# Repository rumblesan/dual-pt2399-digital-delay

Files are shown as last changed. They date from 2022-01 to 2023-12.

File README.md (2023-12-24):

# Dual PT2399 Digi Delay

A delay module designed for the Loudest Warning 4U format

## Description

Built around two PT2399 delay chips.
Inspired equally by the Serge WAD and the Strega, it does clean pretty well but also pushes into the usual 2399 weirdness.

## Features

 * Dual PT2399 delays
 * Single input with gain control and mild overdrive when past about 1 o'clock
 * Switch to have delays in series or parallel
 * Delay can go from short as I think I could manage to well into clicks and squeals territory
 * CV control over delay time of each independently, with attenuverters
 * CV control has an input range of -5 to +5 volts, which should cover the full range of the delay either way
 * Join switch to have delay 1 CV/knob control affect delay 2 as well
 * Independent full wet outputs for each delay
 * Independent mix levels for each delay and dry into main mix out, with additional overdrive on the delays when pushed past about 1 o'clock
 * Feedback can very easily push into self oscillation territory

## Power

+12 101ma
-12 35ma

## Signal Flow

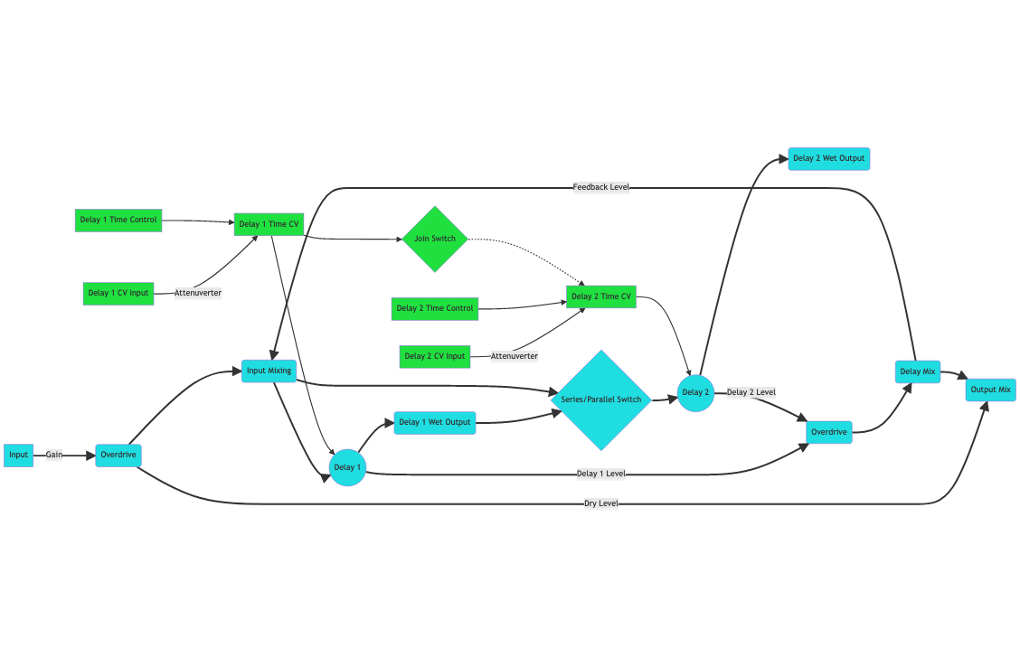
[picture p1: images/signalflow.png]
Signal flow diagram


## Front Panel

In the [panel](./panel) folder there are Front Panel Design files that can be used to order aluminium panels. One has the oval holes that fit the Johnson banana plugs, whilst the other just has circular holes.

There are also gerber files for a PCB front panel if required.

The Affinity Design and Inkscape SVG files are included in the repository as well in case you want to redesign things.

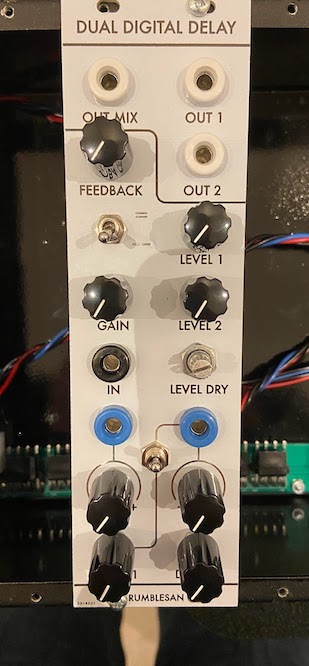
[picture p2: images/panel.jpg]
Module front panel


## Part Information

Everything *should* be pretty clear and obvious as far as construction goes, but the following may be useful info.

### Capacitors

Caps noted as X7R are ones that are for power decoupling. Feel free to use C0G ones if you want.
Caps noted as polypropylene are used in the input and output filters of the PT2399 delay chip. Any decent film should be fine, but you can probably use C0G ceramics if you want.
Electrolytic caps noted as audio are ones that are in the audio path, so worth getting decent quality ones.

### Banana Jacks

Designed to work with the Johnson banana jacks, but others probably work.

### Power Connector

The PCB footprint for the power connector is for a Molex KK-254 connector. In reality I've assumed people with likely have a flying cable with whatever they use on the end.

## Construction Notes

The boards sandwich together with all components inside. This means that all the capacitors on the delay board need to be lying flat against the PCB.

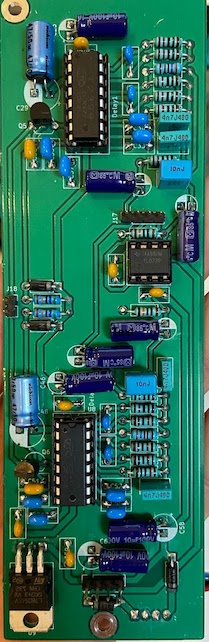
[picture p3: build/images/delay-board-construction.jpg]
Delay board construction


Depending on what part you use for the Join switch, the lower leg from that may extend far enough to hit IC U5 on the mid board, so snip it off.

## Fixes

Some of the older revisions have some minor errors. Check the [Fixes](./build/fixes.md) file for more information.

## Availability

[Pusherman](https://pushermanproductions.com/product/4u-rumblesan-dual-pt2399-digital-delay-3-x-pcb-fr4-panel/)
Synthcube coming soon

## Contact

Drop me an email at guy@rumblesan.com

## License

Creative Commons Licence
This work is licensed under a [Creative Commons Attribution 4.0 International License]("http://creativecommons.org/licenses/by/4.0/")

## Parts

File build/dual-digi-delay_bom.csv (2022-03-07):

Component | Description | Part | References | Value | Footprint | Quantity Per PCB | Vendor | Note | SKU
1 | Unpolarized capacitor | C | C2 C3 C7 C8 C9 C11 C17 C18 C19 C20 C23 C24 | 10pF | C_Rect_L7.0mm_W3.5mm_P5.00mm | 12
2 | Unpolarized capacitor | C | C13 C14 | 100pF | C_Rect_L7.0mm_W3.5mm_P5.00mm | 2
3 | Unpolarized capacitor | C | C27 C28 C49 C50 | 560pF | C_Rect_L7.0mm_W3.5mm_P5.00mm | 4
4 | Unpolarized capacitor | C | C30 C33 C35 C37 C52 C54 C55 C57 | 100nF | C_Rect_L7.0mm_W3.5mm_P5.00mm | 8
5 | Polarized capacitor | C_Polarized | C25 C46 C58 C60 | 10uF | CP_Radial_D6.3mm_P2.50mm | 4
6 | Polarized capacitor | C_Polarized | C29 C48 | 47uF | CP_Radial_D8.0mm_P3.50mm | 2
7 | Unpolarized capacitor | C | C1 C4 C5 C6 C10 C12 C15 C16 C21 C22 C26 C40 C41 C47 C56 C59 | 100nF (X7R) | C_Rect_L7.0mm_W3.5mm_P5.00mm | 16
8 | Unpolarized capacitor | C | C36 C45 | 10nF (polypropylene) | C_Rect_L7.0mm_W3.5mm_P5.00mm | 2
9 | Polarized capacitor | C_Polarized | C38 C39 C42 C43 | 10uF (Audio) | CP_Radial_D5.0mm_P2.50mm | 4
10 | Unpolarized capacitor | C | C32 C51 | 470nF (X7R) | C_Rect_L7.0mm_W3.5mm_P5.00mm | 2
11 | Unpolarized capacitor | C | C31 C34 C44 C53 | 4n7F (polypropylene) | C_Rect_L7.0mm_W3.5mm_P5.00mm | 4
12 | Diode | D | D1 D2 D3 D4 D5 D6 D7 D8 D9 D10 D11 D12 | 1N4148 | Diode_THT_P7.62mm_Horizontal | 12
13 | Diode | D | D15 D16 | 1N5818 | D_A-405_P10.16mm_Horizontal | 2
14 | Diode | D | D13 D14 | 1n4001 | D_A-405_P10.16mm_Horizontal | 2
15 | Potentiometer | R_Potentiometer | DELAY_CV_ATTV1 DELAY_CV_ATTV2 | 100kB | Potentiometer_Alpha_RD901F-40-00D_Single_Vertical_CircularHoles | 2 | Thonk
16 | Potentiometer | R_Potentiometer | DELAY_TIME1 DELAY_TIME2 | 25kB | Potentiometer_Alpha_RD901F-40-00D_Single_Vertical_CircularHoles | 2 | Thonk
17 | Potentiometer | R_Potentiometer | DRY_LEVEL1 FEEDBACK1 INPUT_GAIN1 WET_LEVEL1 WET_LEVEL2 | 50kB | Potentiometer_Alpha_RD901F-40-00D_Single_Vertical_CircularHoles | 5 | Thonk
18 | A Johnson panel mount banana jack | BananaJack_PanelMount | J1 J2 J3 J4 J5 J6 | BananaJack_PanelMount | BananaJack_THT_JohnsonCinch_108-09 | 6 | Mouser | BananaJack | 108-0901-1
19 | Generic connector, single row, 01x02, script generated (kicad-library-utils/schlib/autogen/connector/) | Conn_01x02_Male | J23 J25 J28 J31 | Conn_1x02_Pin | PinHeader_1x02_P2.54mm_Vertical | 4 |  | Delay Time Control Delay Out Output Audio Feedback Audio
20 | Generic connector, single row, 01x02, script generated (kicad-library-utils/schlib/autogen/connector/) | Conn_01x02_Female | J7 J8 J9 J18 | Conn_1x02_Skt | PinSocket_1x02_P2.54mm_Vertical | 4 |  | Output Audio Delay Out Feedback Audio Delay Time Control
21 | Generic connector, single row, 01x03, script generated (kicad-library-utils/schlib/autogen/connector/) | Conn_01x03_Male | J29 | Conn_1x03_Pin | PinHeader_1x03_P2.54mm_Vertical | 1 |  | Delay2 Source
22 | Generic connector, single row, 01x03, script generated (kicad-library-utils/schlib/autogen/connector/) | Conn_01x03_Female | J11 | Conn_1x03_Skt | PinSocket_1x03_P2.54mm_Vertical | 1 |  | Delay2 Source
23 | Generic connector, single row, 01x04, script generated (kicad-library-utils/schlib/autogen/connector/) | Conn_01x04_Male | J16 J24 J26 J30 J32 | Conn_1x04_Pin | PinHeader_1x04_P2.54mm_Vertical | 5 |  | Delay Send/Recv Mid Board Power Recv Delay Audio Top Board Power Recv Input Audio
24 | Generic connector, single row, 01x04, script generated (kicad-library-utils/schlib/autogen/connector/) | Conn_01x04_Female | J10 J12 J15 J17 J19 | Conn_1x04_Skt | PinSocket_1x04_P2.54mm_Vertical | 5 |  | Delay Audio Input Audio Mid Board Power Send Delay Send/Recv Lower Board Power Send
25 | Generic connector, single row, 01x06, script generated (kicad-library-utils/schlib/autogen/connector/) | Conn_01x06_Male | J27 J33 | Conn_1x06_Pin | PinHeader_1x06_P2.54mm_Vertical | 2 |  | Delay2 CV Delay1 CV
26 | Generic connector, single row, 01x06, script generated (kicad-library-utils/schlib/autogen/connector/) | Conn_01x06_Female | J13 J14 | Conn_1x06_Skt | PinSocket_1x06_P2.54mm_Vertical | 2 |  | Delay1 CV Delay2 CV
27 | Generic connector, single row, 01x04, script generated (kicad-library-utils/schlib/autogen/connector/) | Conn_01x04_Male | J20 | Molex_1x04_KK-254 | Molex_KK-254_AE-6410-04A_1x04_P2.54mm_Vertical | 1 |  | Main Power
28 | 0.2A Ic, 40V Vce, Small Signal NPN Transistor, TO-92 | 2N3904 | Q1 Q2 Q3 Q4 Q5 Q6 | 2N3904 | TO-92_Inline_Wide | 6
29 | Resistor | R | R1 R4 R8 | 330r | Resistor_THT_L6.3mm_D2.5mm_P10.16mm_Horizontal | 3
30 | Resistor | R | R19 R20 | 470r | Resistor_THT_L6.3mm_D2.5mm_P10.16mm_Horizontal | 2
31 | Resistor | R | R24 R25 R50 R51 | 1k | Resistor_THT_L6.3mm_D2.5mm_P10.16mm_Horizontal | 4
32 | Resistor | R | R26 R29 | 2k2 | Resistor_THT_L6.3mm_D2.5mm_P10.16mm_Horizontal | 2
33 | Resistor | R | R54 R66 | 2k7 | Resistor_THT_L6.3mm_D2.5mm_P10.16mm_Horizontal | 2
34 | Resistor | R | R2 R7 R46 R48 R52 R53 R55 R56 R57 R58 R63 R64 R65 R67 R68 R69 | 10k | Resistor_THT_L6.3mm_D2.5mm_P10.16mm_Horizontal | 16
35 | Resistor | R | R3 R11 | 15k | Resistor_THT_L6.3mm_D2.5mm_P10.16mm_Horizontal | 2
36 | Resistor | R | R30 R32 | 22k | Resistor_THT_L6.3mm_D2.5mm_P10.16mm_Horizontal | 2
37 | Resistor | R | R17 | 33k | Resistor_THT_L6.3mm_D2.5mm_P10.16mm_Horizontal | 1
38 | Resistor | R | R12 R13 R40 R41 R42 R43 | 47k | Resistor_THT_L6.3mm_D2.5mm_P10.16mm_Horizontal | 6
39 | Resistor | R | R44 R45 | 82k | Resistor_THT_L6.3mm_D2.5mm_P10.16mm_Horizontal | 2
40 | Resistor | R | R5 R6 R9 R10 R14 R15 R16 R18 R27 R28 R33 R34 R37 R38 R39 R47 R49 R59 R61 | 100k | Resistor_THT_L6.3mm_D2.5mm_P10.16mm_Horizontal | 19
41 | Resistor | R | R21 R31 R35 R36 | 220k | Resistor_THT_L6.3mm_D2.5mm_P10.16mm_Horizontal | 4
42 | Resistor | R | R22 R23 R60 R62 | 560k | Resistor_THT_L6.3mm_D2.5mm_P10.16mm_Horizontal | 4
43 | Switch, single pole double throw | SW_SPDT | SW1 SW2 | SW_SPDT | Toggle_Switch_100SP1T1B3M2QE | 2 | Mouser | Delay 2 Input CV Join | 612-100SP1T1B3M2QEH
44 | Positive 1.5A 35V Linear Regulator, Fixed Output 5V, TO-220/TO-263/TO-252 | L7805 | U9 | L7805 | TO-220-3_Horizontal_TabDown | 1
45 | Echo Processor IC | PT2399 | U6 U8 | PT2399 | DIP-16_W7.62mm_Socket | 2
46 | Dual Low-Noise JFET-Input Operational Amplifiers, DIP-8/SOIC-8 | TL072 | U1 U2 U3 U7 | TL072 | DIP-8_W7.62mm_Socket | 4
47 | Quad Low-Noise JFET-Input Operational Amplifiers, DIP-14/SOIC-14 | TL074 | U4 U5 | TL074 | DIP-14_W7.62mm_Socket | 2
Component Groups: | 47
Component Count: | 202
Fitted Components: | 202
Number of PCBs: | 1
Total components: | 202
Schematic Version: | v05
Schematic Date: | 2022-03-04
PCB Variant: | udefault
BoM Date: | Monday, 07 March 2022 at 15:22:20
Schematic Source: | dual-digi-delay.kicad_sch
KiCad Version: | Eeschema (6.0.0-0)

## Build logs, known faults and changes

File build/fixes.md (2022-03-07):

# Fixes

Fixes and caveats for any versions of the PCB that need them.

## Revision 5

No errors so far.

## Revision 4

The silkscreen for J16 is on the wrong side of the board. Make sure to install the pin header on the other side.

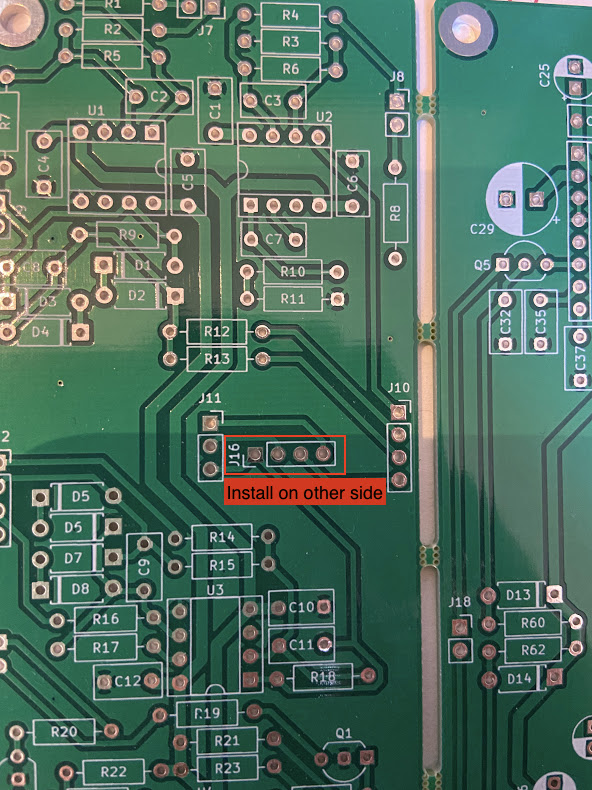
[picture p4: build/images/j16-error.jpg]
Revision 4 J16 fix


## Revision 3

The D16 polarity protection diode symbol is reversed on the PCB. Make sure to install with the cathode going to the power input.

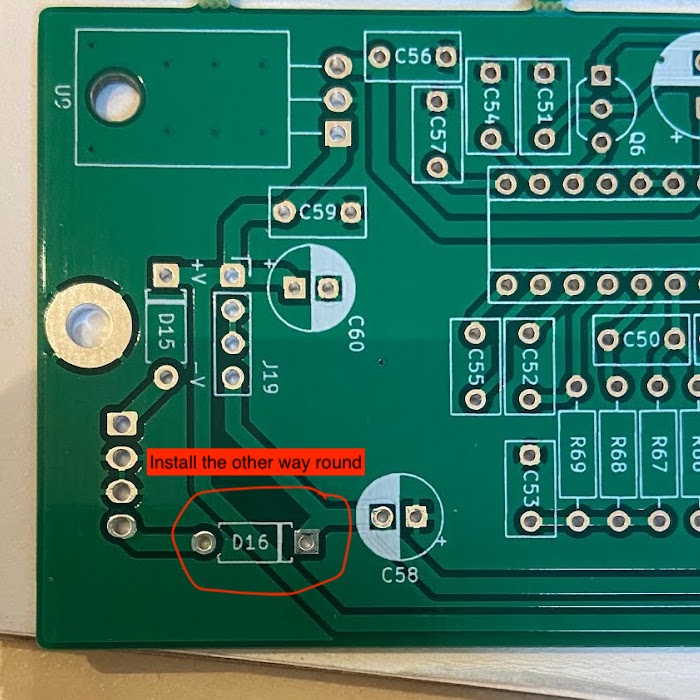
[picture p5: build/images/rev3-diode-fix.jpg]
Revision 3 diode fix


Also J16 error present in rev4 above.

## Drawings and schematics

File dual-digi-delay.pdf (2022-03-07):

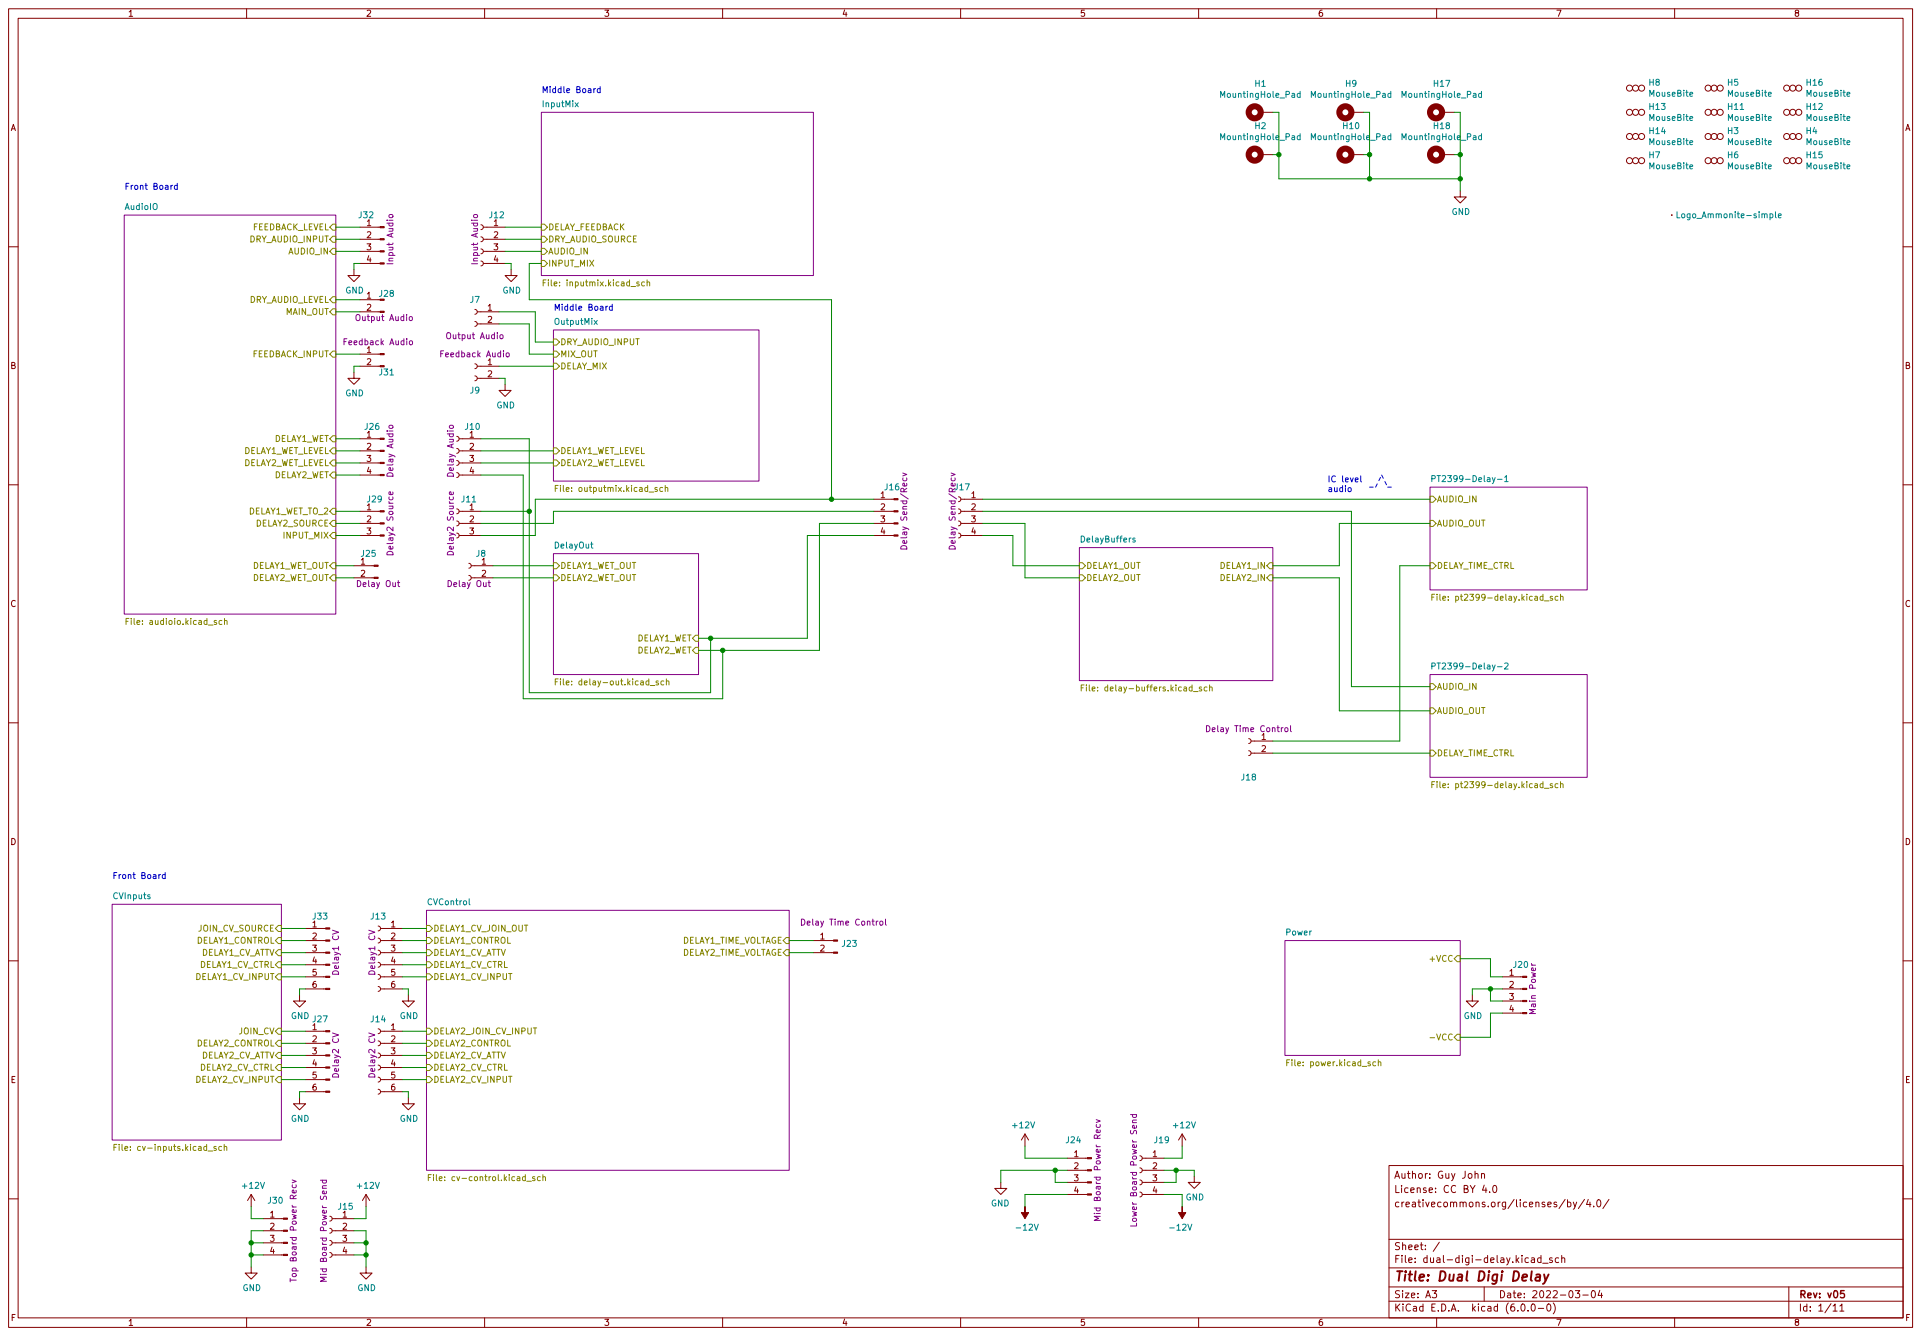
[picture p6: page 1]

H7MouseBite GND
File: delay-out.kicad_sch DELAY_MIX MIX_OUT DRY_AUDIO_INPUT DELAY2_WET_LEVEL DELAY1_WET_LEVEL OutputMix

File: delay-buffers.kicad_sch DELAY1_WET DELAY2_WET DELAY1_WET_OUT DELAY2_WET_OUT DelayOut

J18 Delay Time Control GND

File: dual-digi-delay.kicad_sch Sheet: / creativecommons.org/licenses/by/4.0/ License: CC BY 4.0 Author: Guy John DELAY1_CV_INPUT DELAY1_CV_ATTV

J19 Lower Board Power Send+12V

J30 Top Board Power Recv+12V
J15 Mid Board Power Send GND

Id: 1/11 Title: Dual Digi Delay

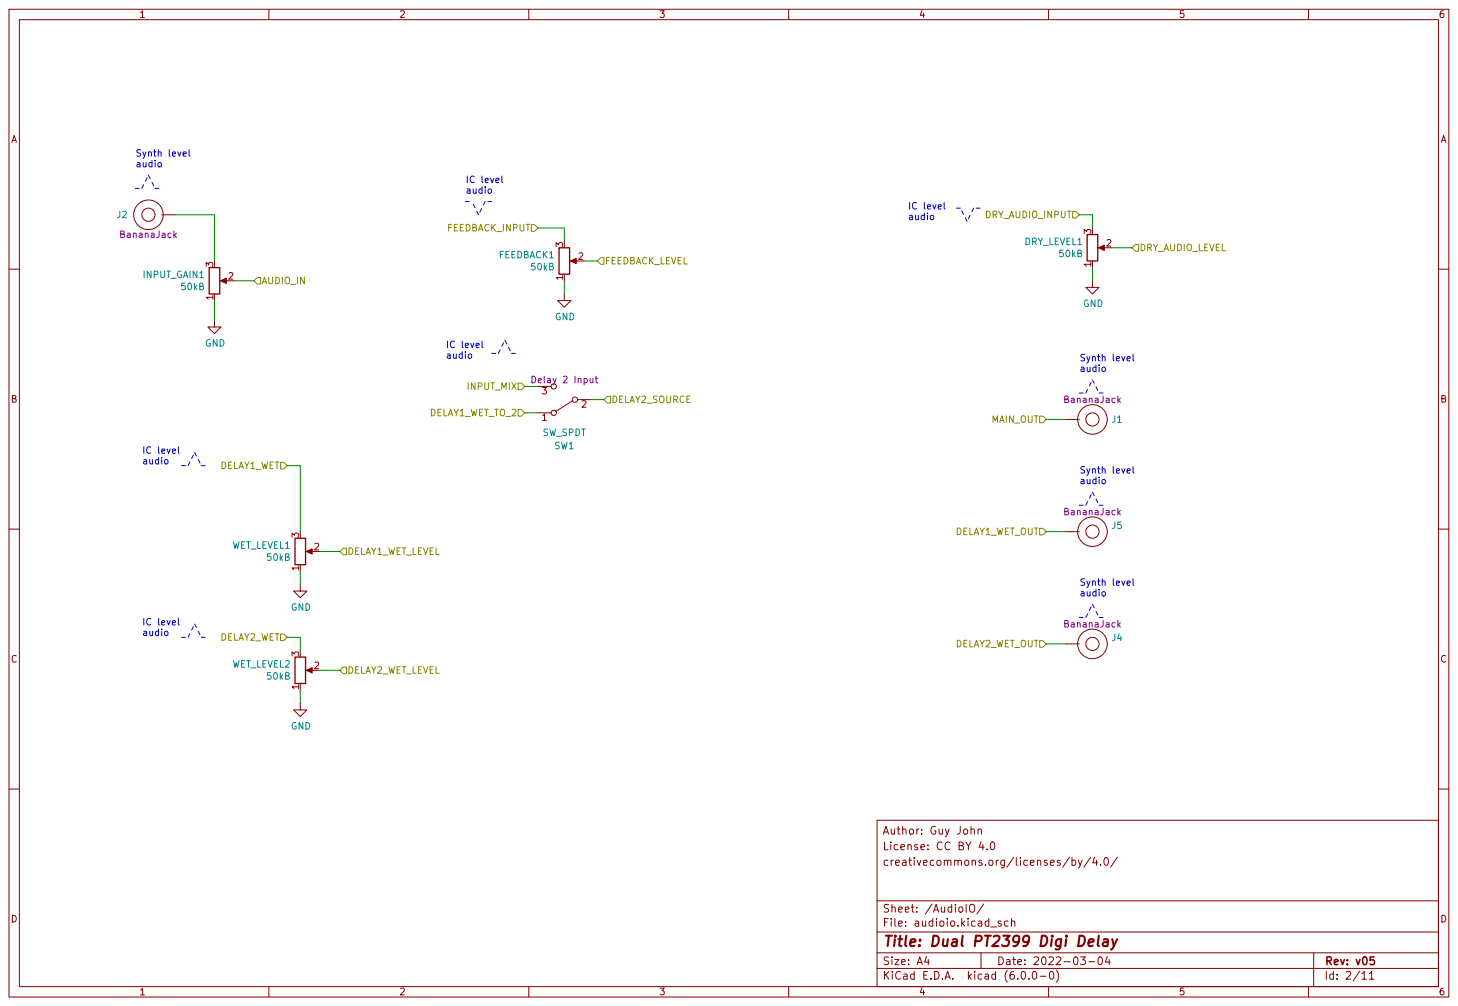
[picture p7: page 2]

File: audioio.kicad_sch Sheet: /AudioIO/ creativecommons.org/licenses/by/4.0/ License: CC BY 4.0 Author: Guy John

Id: 2/11 Title: Dual PT2399 Digi Delay

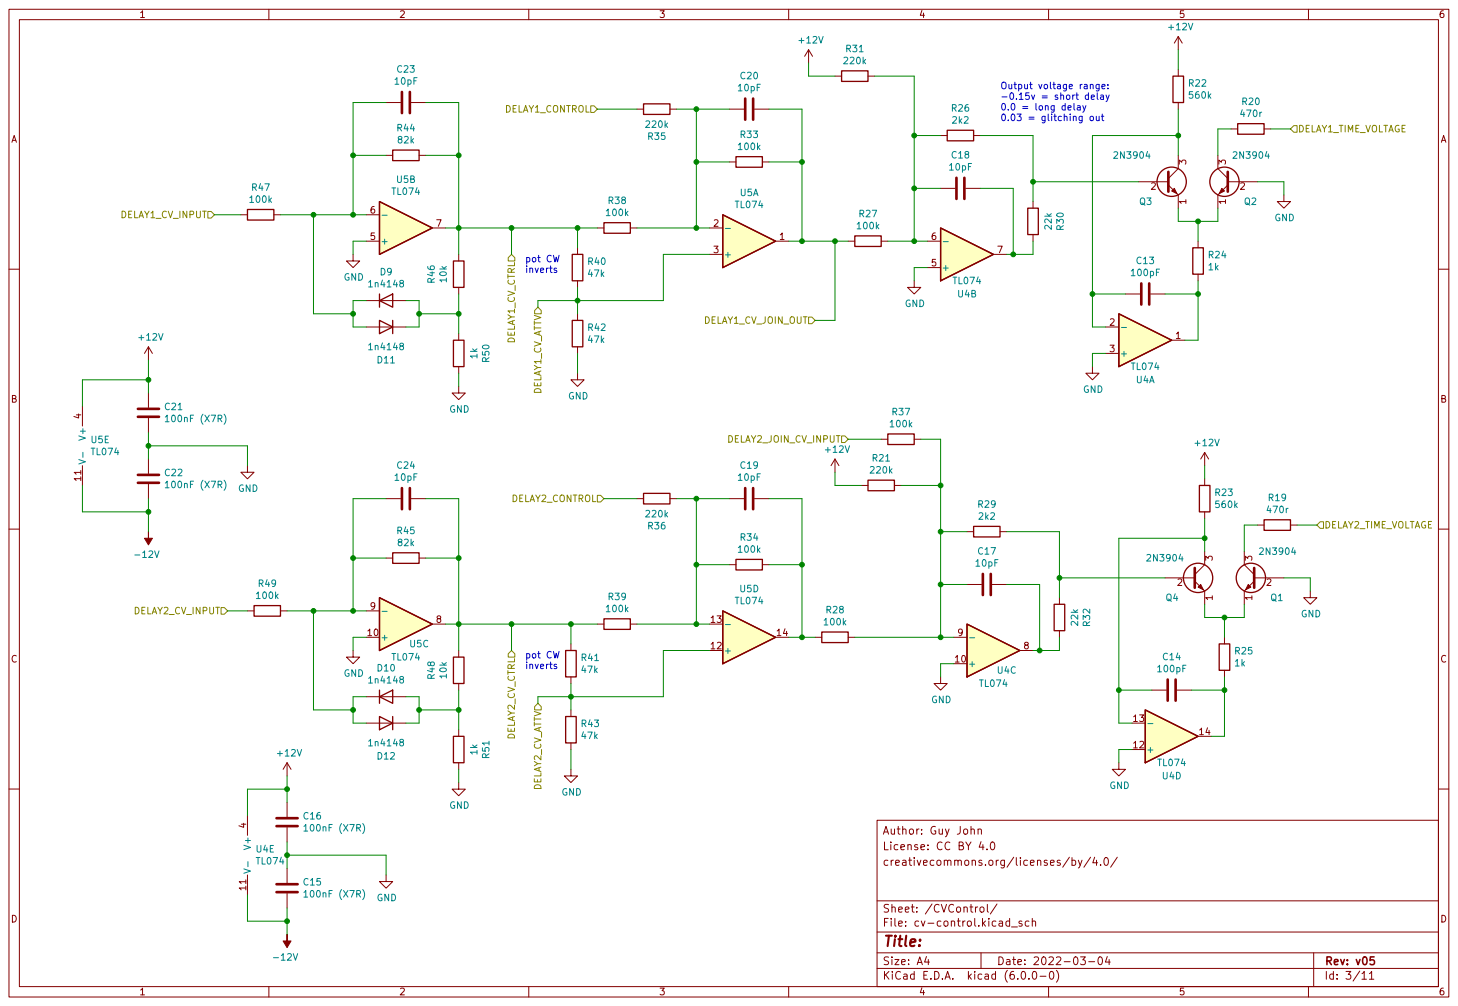
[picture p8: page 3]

File: cv-control.kicad_sch Sheet: /CVControl/ creativecommons.org/licenses/by/4.0/ License: CC BY 4.0 Author: Guy John

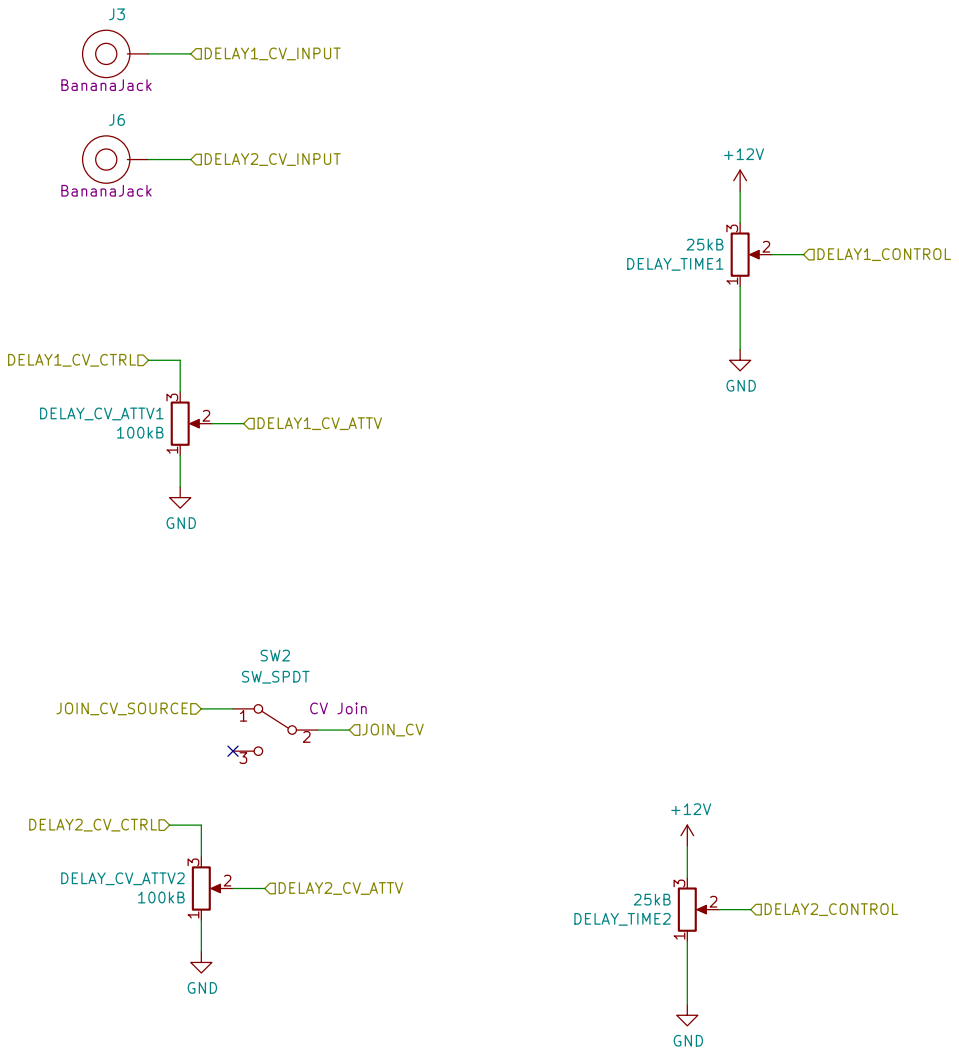
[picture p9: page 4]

creativecommons.org/licenses/by/4.0/ License: CC BY 4.0 Author: Guy John

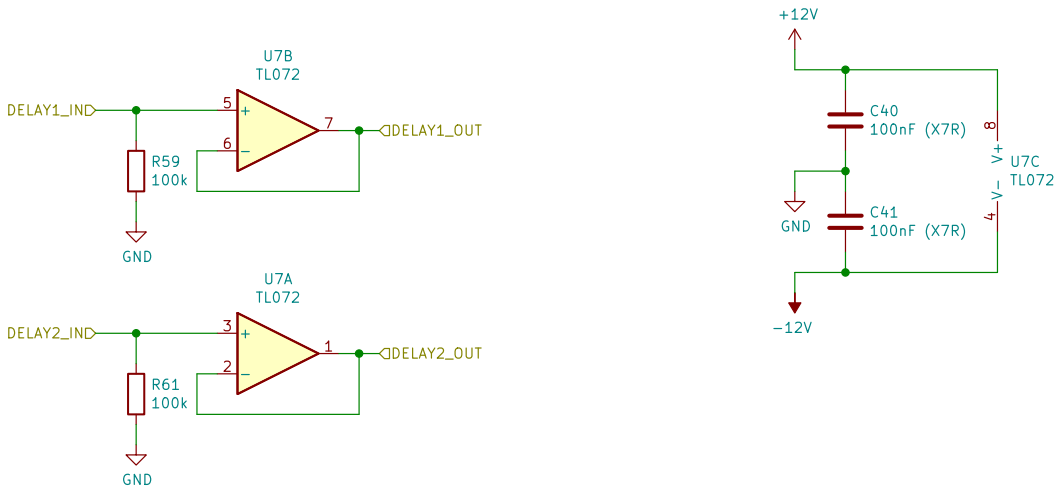
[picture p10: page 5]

creativecommons.org/licenses/by/4.0/ License: CC BY 4.0 Author: Guy John GND

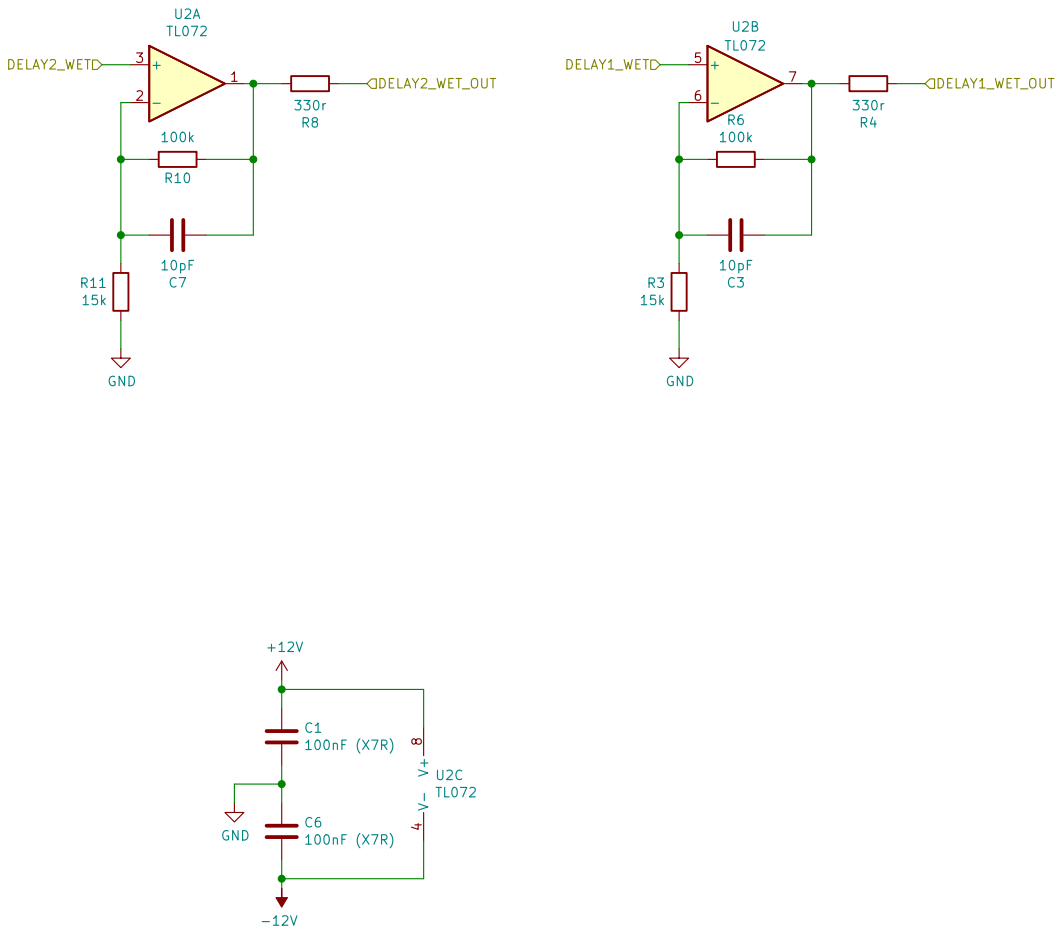
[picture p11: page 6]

creativecommons.org/licenses/by/4.0/ License: CC BY 4.0 Author: Guy John

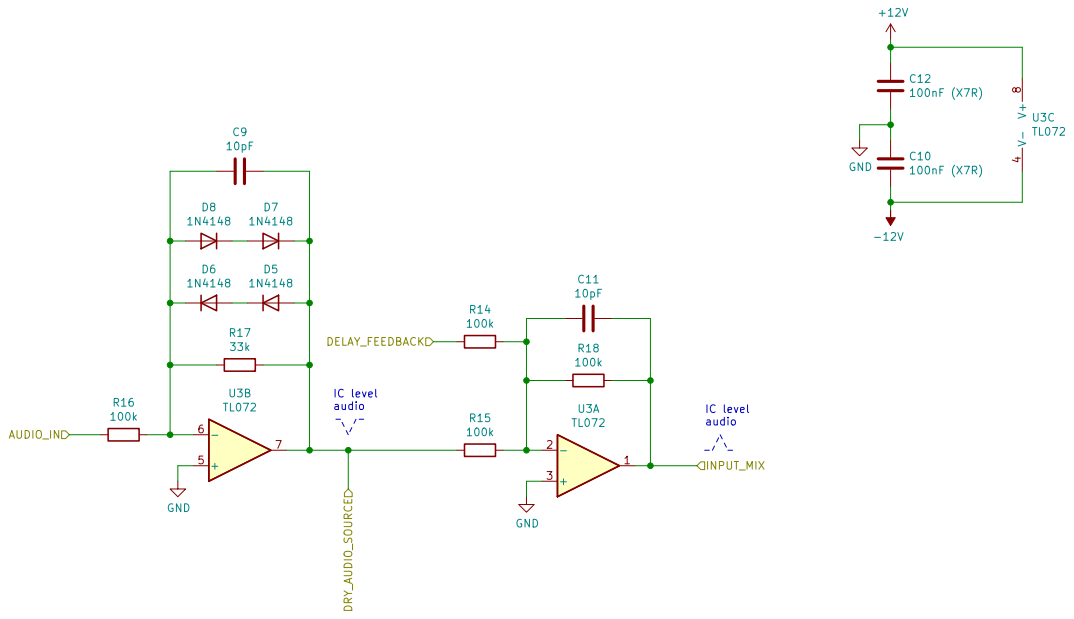
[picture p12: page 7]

creativecommons.org/licenses/by/4.0/ License: CC BY 4.0 Author: Guy John R16

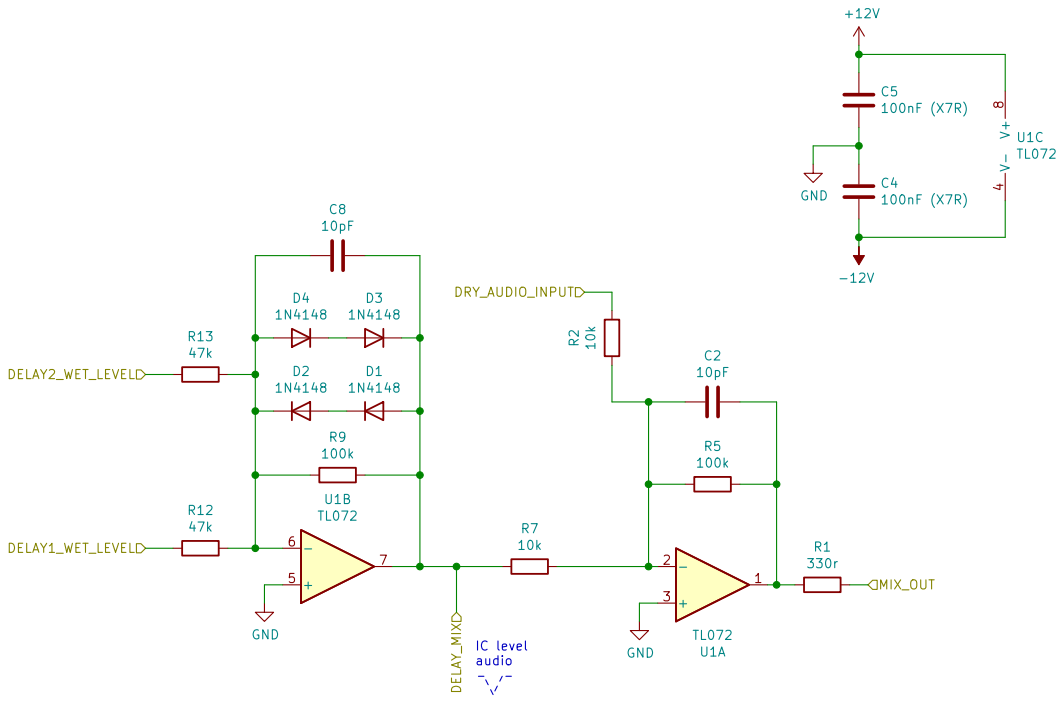
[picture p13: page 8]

creativecommons.org/licenses/by/4.0/ License: CC BY 4.0 Author: Guy John R12

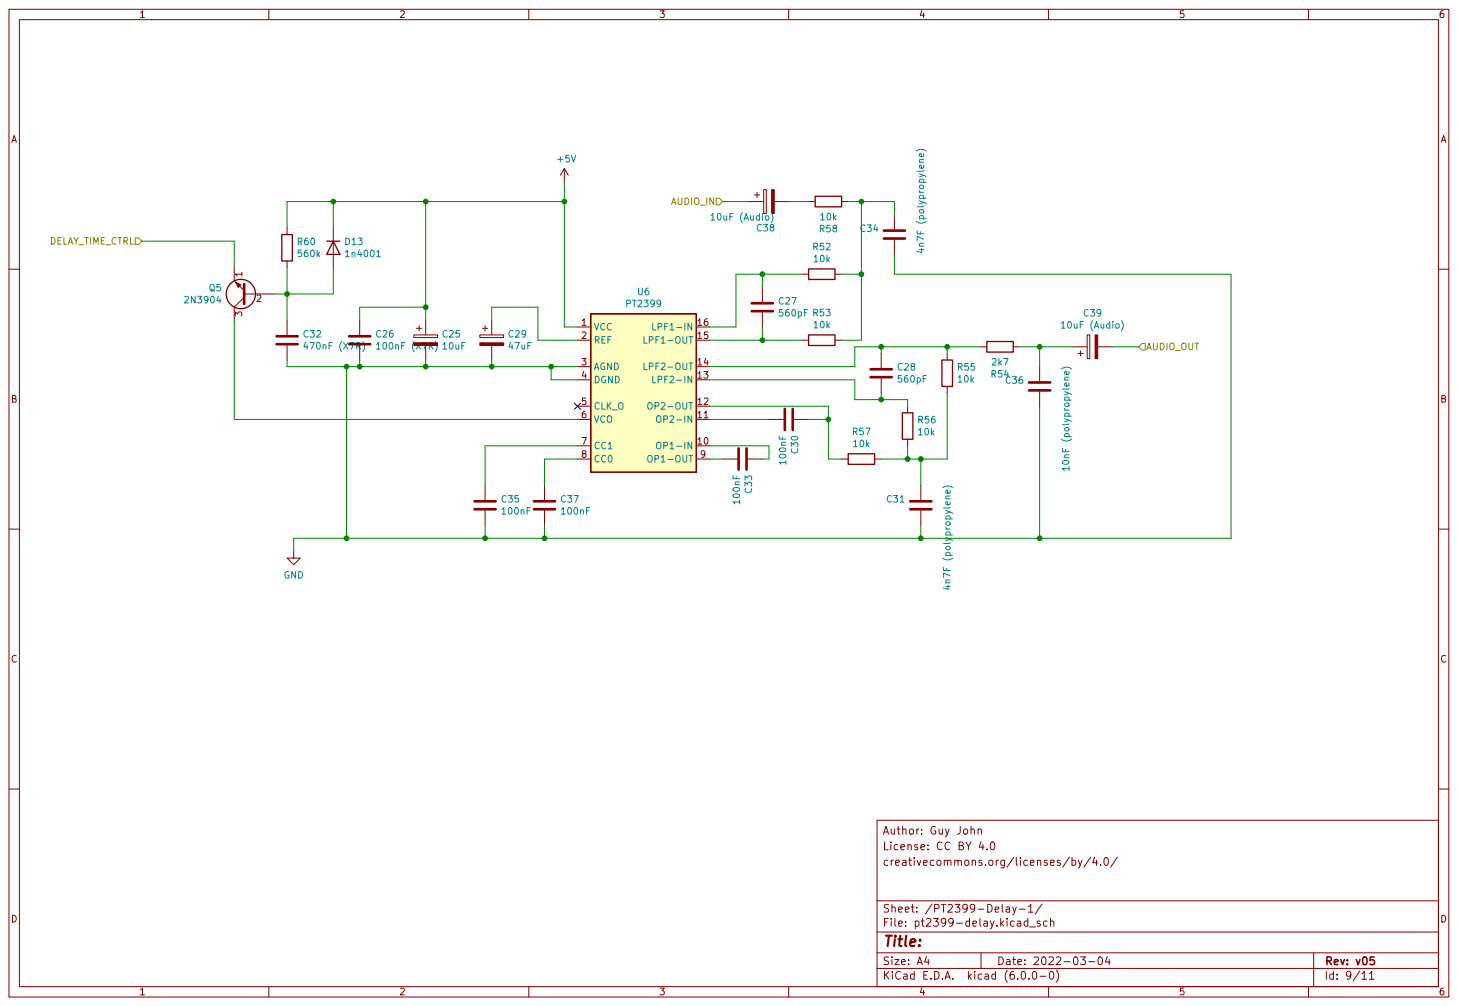
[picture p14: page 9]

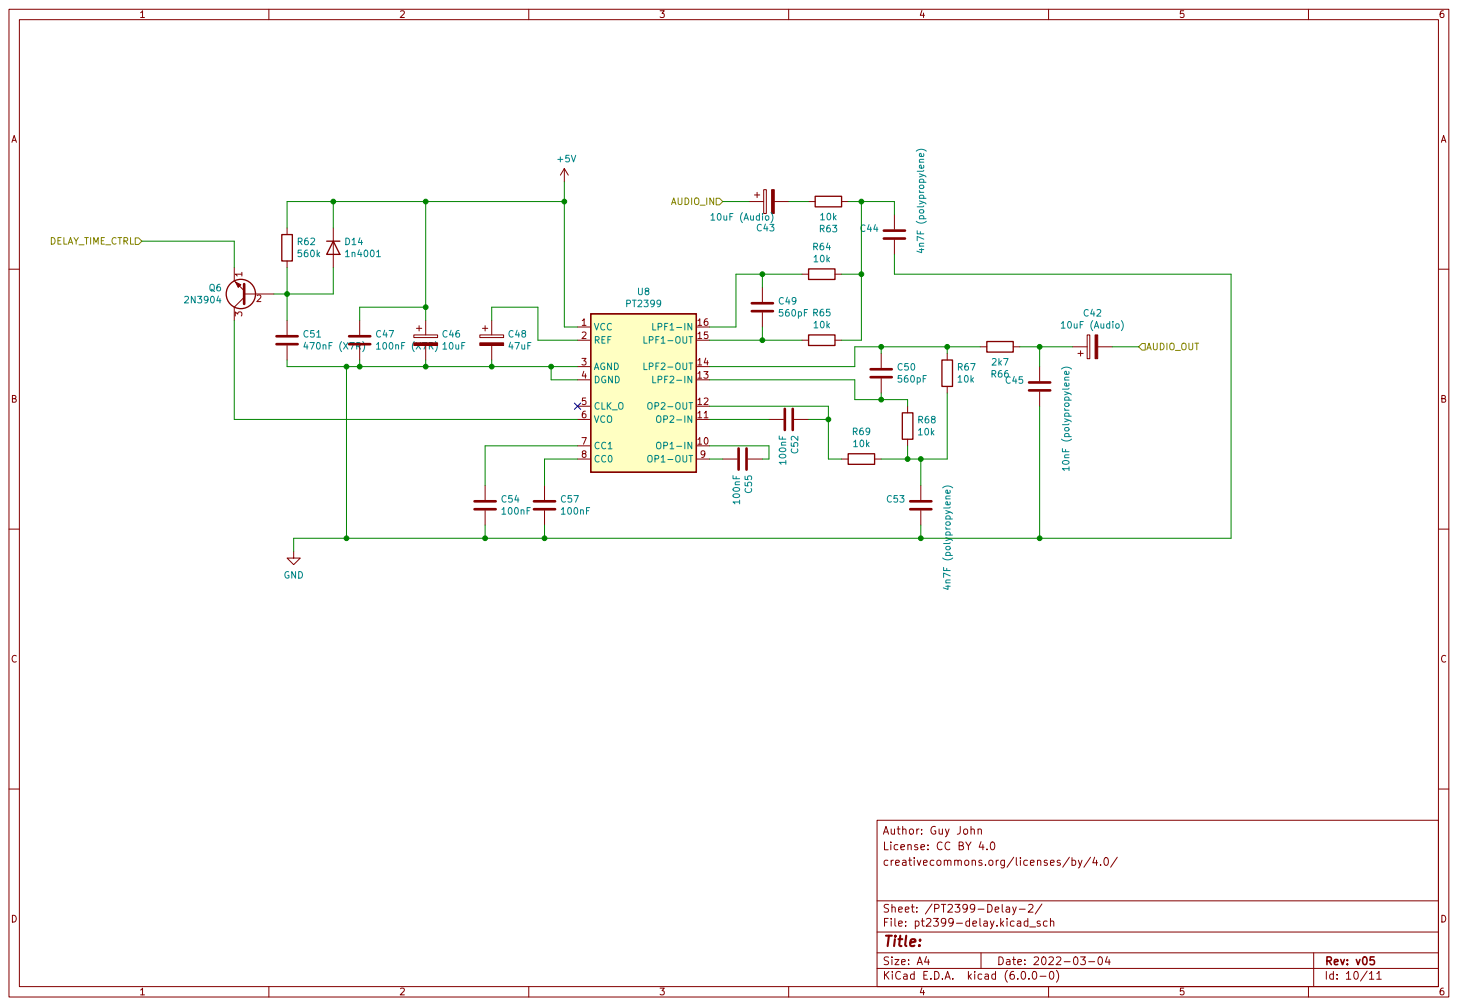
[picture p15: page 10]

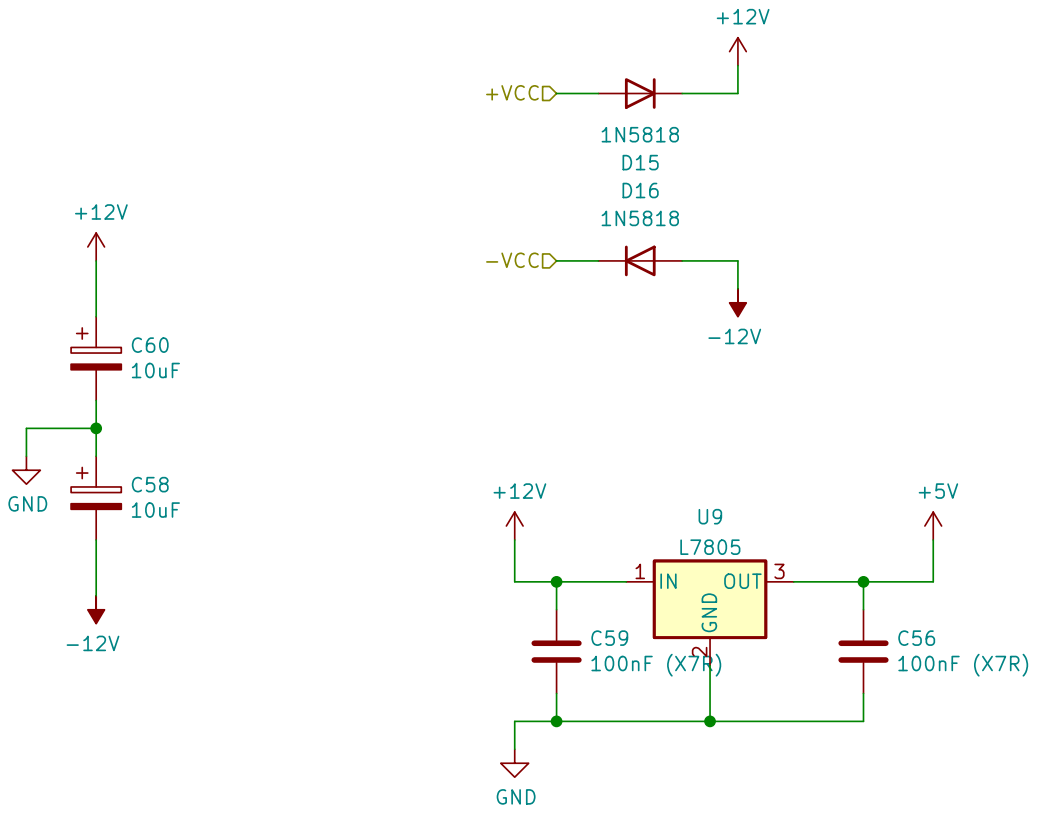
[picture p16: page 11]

File: power.kicad_sch Sheet: /Power/ creativecommons.org/licenses/by/4.0/ License: CC BY 4.0 Author: Guy John

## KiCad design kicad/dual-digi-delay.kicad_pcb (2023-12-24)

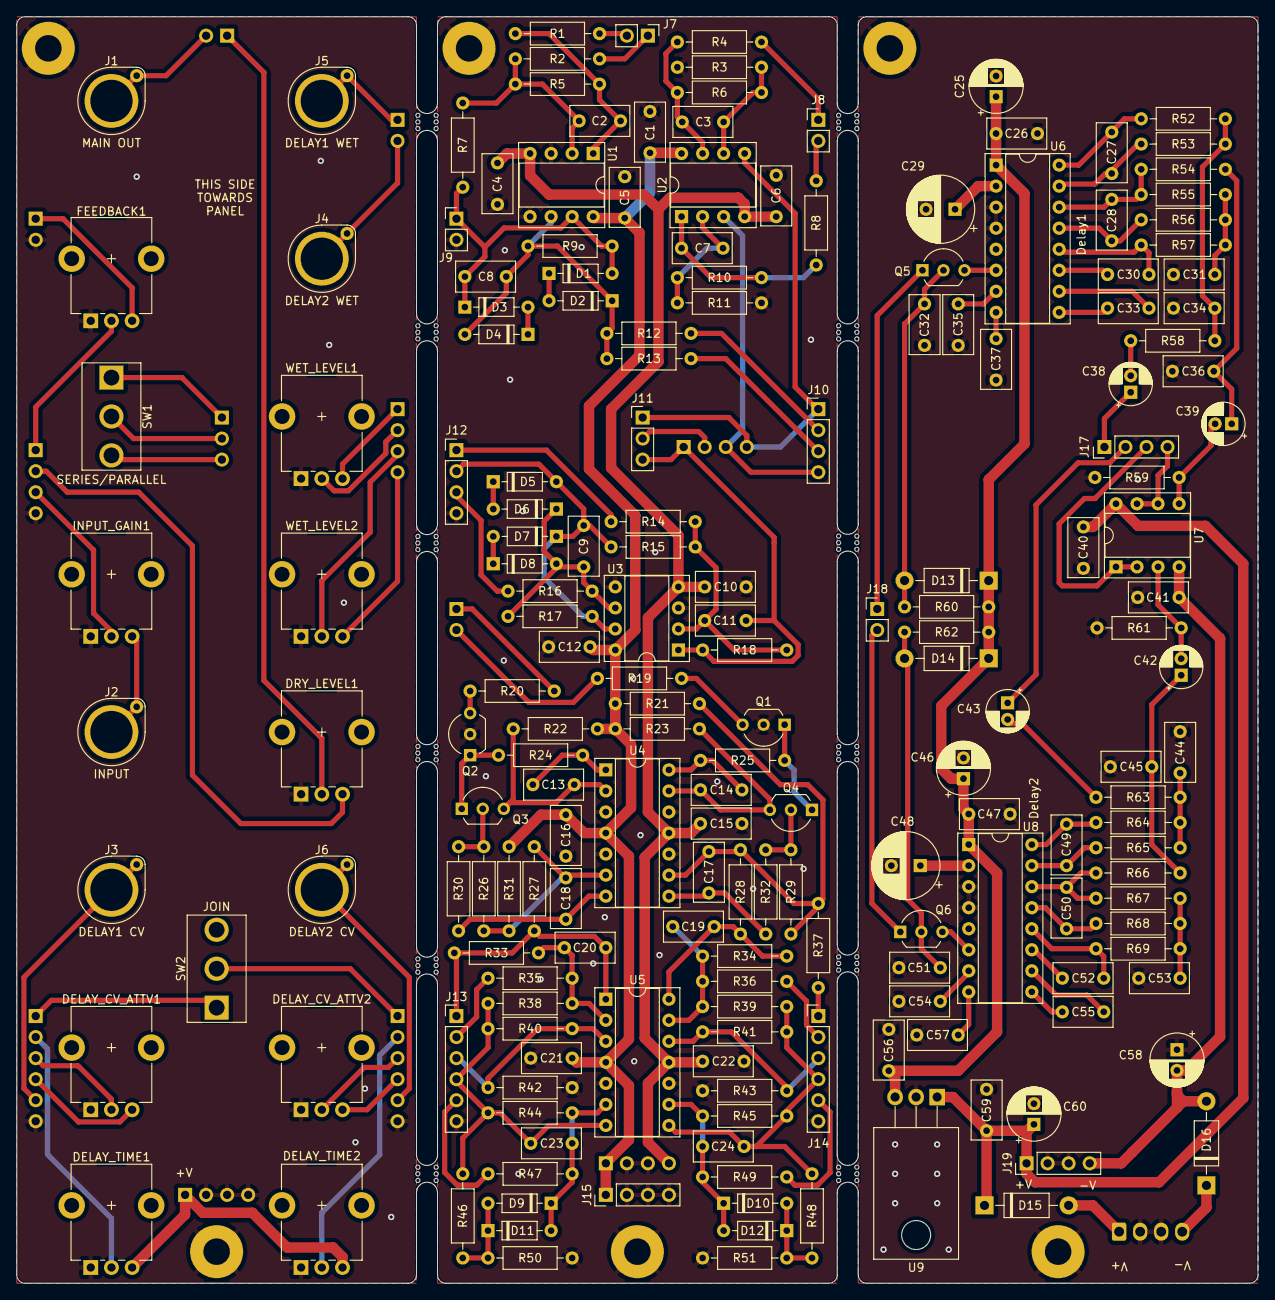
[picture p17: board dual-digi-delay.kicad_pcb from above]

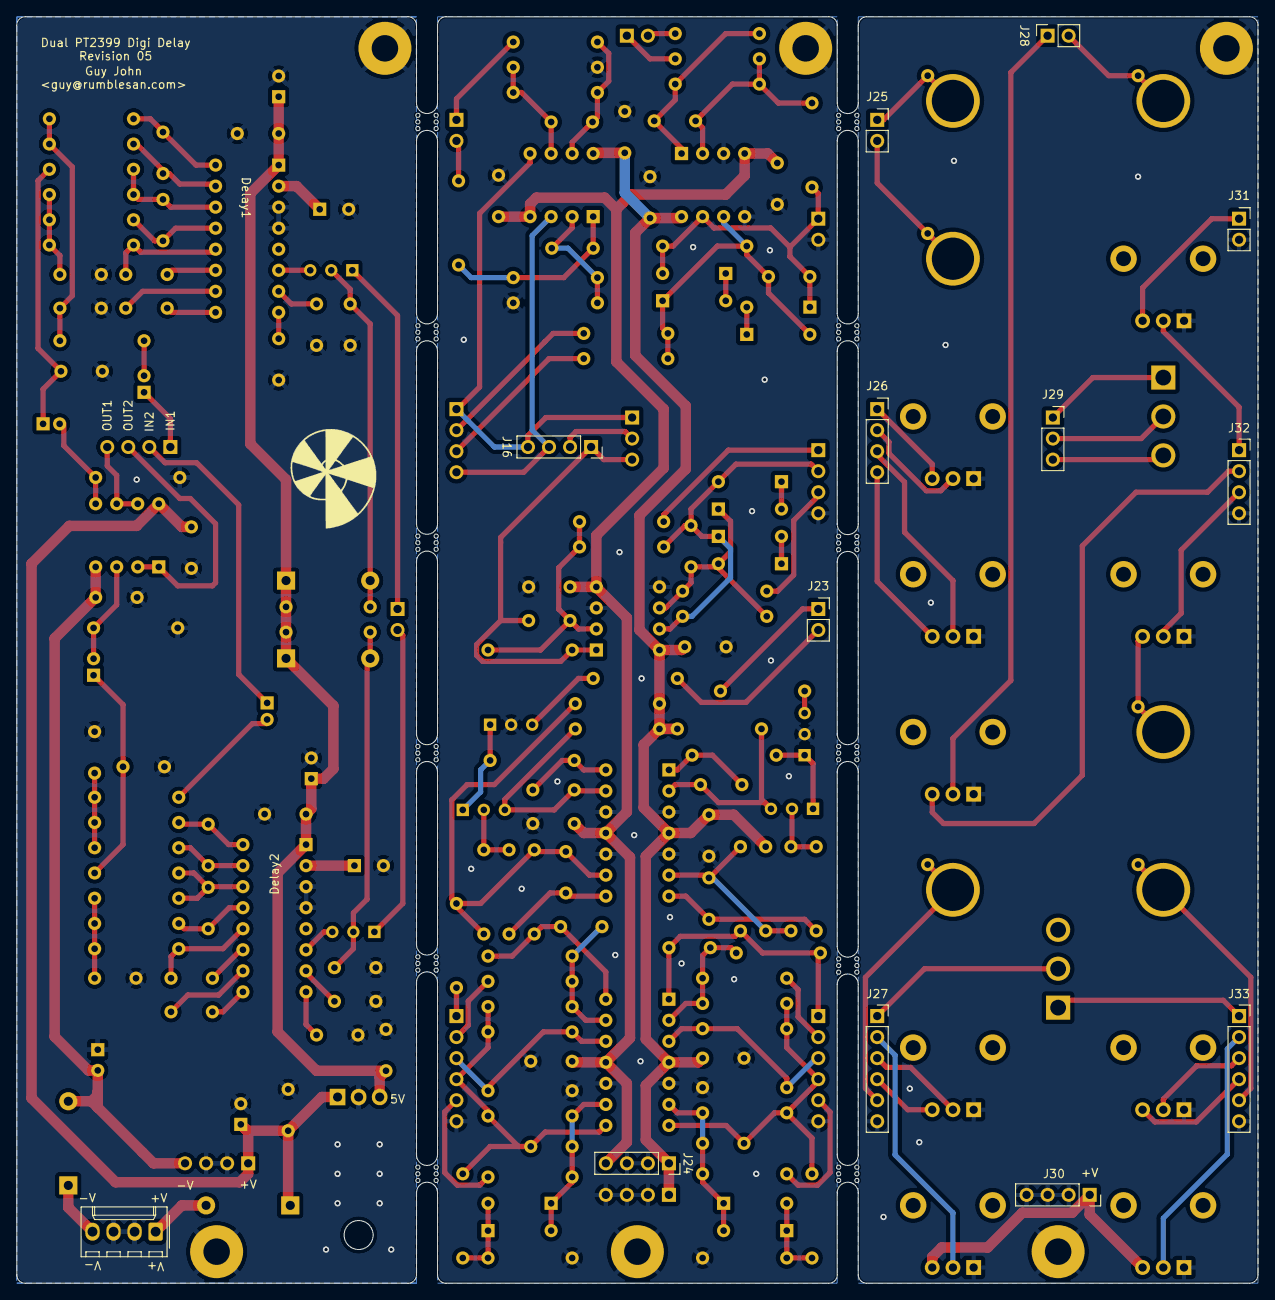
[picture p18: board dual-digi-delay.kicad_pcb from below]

Board: 2 copper layers, 149.9 x 152.9 mm, 221 parts (14 on the bottom side), 134 nets.

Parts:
C1, C4, C5, C6, C10, C12, C15, C16, C21, C22, C26, C30, C33, C35, C37, C40, C41, C47, C52, C54, C55, C56, C57, C59: 100nF; C_Rect_L7.0mm_W3.5mm_P5.00mm
C2, C3, C7, C8, C9, C11, C13, C14, C17, C18, C19, C20, C23, C24: 10pF; C_Rect_L7.0mm_W3.5mm_P5.00mm
C25, C46, C58, C60: 10uF; CP_Radial_D6.3mm_P2.50mm
C27, C28, C49, C50: 560pF; C_Rect_L7.0mm_W3.5mm_P5.00mm
C29, C48: 47uF; CP_Radial_D8.0mm_P3.50mm
C31, C34, C44, C53: 4n7F; C_Rect_L7.0mm_W3.5mm_P5.00mm
C32, C51: 470nF; C_Rect_L7.0mm_W3.5mm_P5.00mm
C36, C45: 10nF; C_Rect_L7.0mm_W3.5mm_P5.00mm
C38, C39, C42, C43: 10uF; CP_Radial_D5.0mm_P2.00mm
D1, D2, D3, D4, D5, D6, D7, D8, D9, D10, D11, D12: 1N4148; D_DO-35_SOD27_P7.62mm_Horizontal
D13, D14: 1n4001; D_DO-41_SOD81_P10.16mm_Horizontal
D15, D16: 1N5818; D_DO-41_SOD81_P10.16mm_Horizontal
DELAY_CV_ATTV1, DELAY_CV_ATTV2: 100kB; Potentiometer_Alpha_RD901F-40-00D_Single_Vertical_CircularH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
DELAY_TIME1, DELAY_TIME2: 25kB; Potentiometer_Alpha_RD901F-40-00D_Single_Vertical_CircularH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
DRY_LEVEL1: 50kB; Potentiometer_Alpha_RD901F-40-00D_Single_Vertical_CircularH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
FEEDBACK1: 50kB; Potentiometer_Alpha_RD901F-40-00D_Single_Vertical_CircularH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
H1, H2, H9, H10, H17, H18: MountingHole_Pad; MountingHole_3.2mm_M3_Pad
H19: Logo_Ammonite-simple; Logo_Ammonite-simple_small_10.4mmx12.0mm
INPUT_GAIN1: 50kB; Potentiometer_Alpha_RD901F-40-00D_Single_Vertical_CircularH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
J1, J2, J3, J4, J5, J6: BananaJack_PanelMount; BananaJack_THT_JohnsonCinch_108-09
J7, J8, J9, J18: Conn_01x02_Pin; PinHeader_1x02_P2.54mm_Vertical
J10, J12, J15, J17, J19: Conn_01x04_Pin; PinHeader_1x04_P2.54mm_Vertical
J11: Conn_01x03_Pin; PinHeader_1x03_P2.54mm_Vertical
J13, J14: Conn_01x06_Pin; PinHeader_1x06_P2.54mm_Vertical
J16, J24, J26, J30, J32: Conn_01x04_Socket; PinSocket_1x04_P2.54mm_Vertical
J20: 4U_Power; 4u_Power_Molex_KK-254_P2.54mm
J23, J25, J28, J31: Conn_01x02_Socket; PinSocket_1x02_P2.54mm_Vertical
J27, J33: Conn_01x06_Socket; PinSocket_1x06_P2.54mm_Vertical
J29: Conn_01x03_Socket; PinSocket_1x03_P2.54mm_Vertical
Q1, Q2, Q3, Q4, Q5, Q6: 2N3904; TO-92_Inline_Wide
R1, R4, R8: 330r; R_Axial_DIN0207_L6.3mm_D2.5mm_P10.16mm_Horizontal
R2, R7, R46, R48, R52, R53, R55, R56, R57, R58, R63, R64, R65, R67, R68, R69: 10k; R_Axial_DIN0207_L6.3mm_D2.5mm_P10.16mm_Horizontal
R3, R11: 15k; R_Axial_DIN0207_L6.3mm_D2.5mm_P10.16mm_Horizontal
R5, R6, R9, R10, R14, R15, R16, R18, R27, R28, R33, R34, R37, R38, R39, R47, R49, R59, R61: 100k; R_Axial_DIN0207_L6.3mm_D2.5mm_P10.16mm_Horizontal
R12, R13, R40, R41, R42, R43: 47k; R_Axial_DIN0207_L6.3mm_D2.5mm_P10.16mm_Horizontal
R17: 33k; R_Axial_DIN0207_L6.3mm_D2.5mm_P10.16mm_Horizontal
R19, R20: 470r; R_Axial_DIN0207_L6.3mm_D2.5mm_P10.16mm_Horizontal
R21, R31, R35, R36: 220k; R_Axial_DIN0207_L6.3mm_D2.5mm_P10.16mm_Horizontal
R22, R23, R60, R62: 560k; R_Axial_DIN0207_L6.3mm_D2.5mm_P10.16mm_Horizontal
R24, R25, R50, R51: 1k; R_Axial_DIN0207_L6.3mm_D2.5mm_P10.16mm_Horizontal
R26, R29: 2k2; R_Axial_DIN0207_L6.3mm_D2.5mm_P10.16mm_Horizontal
R30, R32: 22k; R_Axial_DIN0207_L6.3mm_D2.5mm_P10.16mm_Horizontal
R44, R45: 82k; R_Axial_DIN0207_L6.3mm_D2.5mm_P10.16mm_Horizontal
R54, R66: 2k7; R_Axial_DIN0207_L6.3mm_D2.5mm_P10.16mm_Horizontal
SW1, SW2: SW_SPDT; Toggle_Switch_100SP-M2
U1, U2, U3, U7: TL072; DIP-8_W7.62mm_Socket
U4, U5: TL074; DIP-14_W7.62mm_Socket
U6, U8: PT2399; DIP-16_W7.62mm_Socket
U9: L7805; TO-220-3_Horizontal_TabDown
WET_LEVEL1, WET_LEVEL2: 50kB; Potentiometer_Alpha_RD901F-40-00D_Single_Vertical_CircularH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
mouse-bite-2.54mm-slot, mouse-bite-2.54mm-slot#2, mouse-bite-2.54mm-slot#3, mouse-bite-2.54mm-slot#4, mouse-bite-2.54mm-slot#5, mouse-bite-2.54mm-slot#6, mouse-bite-2.54mm-slot#7, mouse-bite-2.54mm-slot#8, mouse-bite-2.54mm-slot#9, mouse-bite-2.54mm-slot#10, mouse-bite-2.54mm-slot#11, mouse-bite-2.54mm-slot#12: VAL**; mouse-bite-2.54mm-slot

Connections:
+5V: C25.1, C26.2, C46.1, C47.2, C56.2, D13.1 (K), D14.1 (K), R60.1, R62.1, U6.1 (VCC), U8.1 (VCC), U9.3 (OUT)
+12V: C1.2, C5.2, C12.2, C16.2, C21.2, C40.2, C59.2, C60.1, D15.1 (K), DELAY_TIME1.3, DELAY_TIME2.3, J15.1, J19.1, J24.1, J30.1, R21.2, R22.1, R23.1, R31.2, U1.8 (V+), U2.8 (V+), U3.8 (V+), U4.4 (V+), U5.4 (V+), U7.8 (V+), U9.1 (IN)
-12V: C4.1, C6.1, C10.1, C15.1, C22.1, C41.1, C58.2, D16.2 (A), J19.4, J24.4, U1.4 (V-), U2.4 (V-), U3.4 (V-), U4.11 (V-), U5.11 (V-), U7.4 (V-)
/AudioIO/AUDIO_IN: INPUT_GAIN1.2, J32.3
/AudioIO/DELAY1_WET: J26.1, WET_LEVEL1.3
/AudioIO/DELAY1_WET_LEVEL: J26.2, WET_LEVEL1.2
/AudioIO/DELAY1_WET_OUT: J5.1, J25.1
/AudioIO/DELAY1_WET_TO_2: J29.1, SW1.1 (A)
/AudioIO/DELAY2_SOURCE: J29.2, SW1.2 (B)
/AudioIO/DELAY2_WET: J26.4, WET_LEVEL2.3
/AudioIO/DELAY2_WET_LEVEL: J26.3, WET_LEVEL2.2
/AudioIO/DELAY2_WET_OUT: J4.1, J25.2
/AudioIO/DRY_AUDIO_INPUT: DRY_LEVEL1.3, J32.2
/AudioIO/DRY_AUDIO_LEVEL: DRY_LEVEL1.2, J28.1
/AudioIO/FEEDBACK_INPUT: FEEDBACK1.3, J31.1
/AudioIO/FEEDBACK_LEVEL: FEEDBACK1.2, J32.1
/AudioIO/INPUT_MIX: J29.3, SW1.3 (C)
/AudioIO/MAIN_OUT: J1.1, J28.2
/CVControl/DELAY1_CONTROL: J13.2, R35.1
/CVControl/DELAY1_CV_ATTV: J13.3, R40.1, R42.2, U5.3 (+)
/CVControl/DELAY1_CV_CTRL: C23.1, J13.4, R38.2, R40.2, R44.1, R46.1, U5.7
/CVControl/DELAY1_CV_INPUT: J13.5, R47.2
/CVControl/DELAY1_CV_JOIN_OUT: C20.1, J13.1, R27.2, R33.1, U5.1
/CVControl/DELAY1_TIME_VOLTAGE: J23.1, R20.1
/CVControl/DELAY2_CONTROL: J14.2, R36.1
/CVControl/DELAY2_CV_ATTV: J14.3, R41.1, R43.2, U5.12 (+)
/CVControl/DELAY2_CV_CTRL: C24.1, J14.4, R39.2, R41.2, R45.2, R48.1, U5.8
/CVControl/DELAY2_CV_INPUT: J14.5, R49.1
/CVControl/DELAY2_JOIN_CV_INPUT: J14.1, R37.1
/CVControl/DELAY2_TIME_VOLTAGE: J23.2, R19.1
/CVInputs/DELAY1_CONTROL: DELAY_TIME1.2, J33.2
/CVInputs/DELAY1_CV_ATTV: DELAY_CV_ATTV1.2, J33.3
/CVInputs/DELAY1_CV_CTRL: DELAY_CV_ATTV1.3, J33.4
/CVInputs/DELAY1_CV_INPUT: J3.1, J33.5
/CVInputs/DELAY2_CONTROL: DELAY_TIME2.2, J27.2
/CVInputs/DELAY2_CV_ATTV: DELAY_CV_ATTV2.2, J27.3
/CVInputs/DELAY2_CV_CTRL: DELAY_CV_ATTV2.3, J27.4
/CVInputs/DELAY2_CV_INPUT: J6.1, J27.5
/CVInputs/JOIN_CV: J27.1, SW2.2 (B)
/CVInputs/JOIN_CV_SOURCE: J33.1, SW2.1 (A)
/DelayBuffers/DELAY1_IN: C39.2, R59.1, U7.5 (+)
/DelayBuffers/DELAY1_OUT: J17.4, U7.6 (-), U7.7
/DelayBuffers/DELAY2_IN: C42.2, R61.1, U7.3 (+)
/DelayBuffers/DELAY2_OUT: J17.3, U7.1, U7.2 (-)
/DelayOut/DELAY1_WET: J10.1, J11.1, J16.4, U2.5 (+)
/DelayOut/DELAY1_WET_OUT: J8.1, R4.1
/DelayOut/DELAY2_WET: J10.4, J16.3, U2.3 (+)
/DelayOut/DELAY2_WET_OUT: J8.2, R8.1
/InputMix/AUDIO_IN: J12.3, R16.2
/InputMix/DELAY_FEEDBACK: J12.1, R14.2
/InputMix/DRY_AUDIO_SOURCE: C9.1, D5.2 (A), D7.1 (K), J12.2, R15.2, R17.1, U3.7
/InputMix/INPUT_MIX: C11.1, J11.3, J16.1, R18.1, U3.1
/OutputMix/DELAY1_WET_LEVEL: J10.2, R12.2
/OutputMix/DELAY2_WET_LEVEL: J10.3, R13.2
/OutputMix/DELAY_MIX: C8.1, D1.2 (A), D3.1 (K), J9.1, R7.2, R9.1, U1.7
/OutputMix/DRY_AUDIO_INPUT: J7.1, R2.1
/OutputMix/MIX_OUT: J7.2, R1.1
/PT2399-Delay-1/AUDIO_IN: C38.1, J17.1
/PT2399-Delay-1/DELAY_TIME_CTRL: J18.1, Q5.1 (E)
/PT2399-Delay-2/AUDIO_IN: C43.1, J17.2
/PT2399-Delay-2/DELAY_TIME_CTRL: J18.2, Q6.1 (E)
GND: C1.1, C4.2, C5.1, C6.2, C10.2, C12.1, C15.2, C16.1, C21.1, C22.2, C25.2, C26.1, C29.2, C31.1, C32.2, C34.1, C35.1, C36.1, C37.1, C40.1, C41.2, C44.1, C45.1, C46.2, C47.1, C48.2, C51.2, C53.1, C54.1, C56.1, C57.1, C58.1, C59.1, C60.2, DELAY_CV_ATTV1.1, DELAY_CV_ATTV2.1, DELAY_TIME1.1, DELAY_TIME2.1, DRY_LEVEL1.1, FEEDBACK1.1, H1.1, H2.1, H9.1, H10.1, H17.1, H18.1, INPUT_GAIN1.1, J9.2, J12.4, J13.6, J14.6, J15.2, J15.3, J15.4, J19.2, J19.3, J20.2 (GND), J20.3 (GND), J24.2, J24.3, J27.6, J30.2, J30.3, J30.4, J31.2, J32.4, J33.6, Q1.2 (B), Q2.2 (B), R3.1, R11.1, R42.1, R43.1, R50.1, R51.1, R59.2, R61.2, U1.3 (+), U1.5 (+), U3.3 (+), U3.5 (+), U4.3 (+), U4.5 (+), U4.10 (+), U4.12 (+), U5.5 (+), U5.10 (+), U6.3 (AGND), U6.4 (DGND), U8.3 (AGND), U8.4 (DGND), U9.2 (GND), WET_LEVEL1.1, WET_LEVEL2.1
unnamed: C2.1, R1.2, R5.1, U1.1
unnamed: C3.1, R4.2, R6.1, U2.7
unnamed: C7.1, R8.2, R10.1, U2.1
unnamed: C13.2, R24.2, U4.1
unnamed: C14.2, R25.2, U4.14
unnamed: C17.1, R32.1, U4.8
unnamed: C18.1, R30.1, U4.7
unnamed: C19.1, R28.2, R34.1, U5.14
unnamed: C31.2, R55.1, R56.1, R57.1
unnamed: C34.2, R52.1, R53.1, R58.1
unnamed: C36.2, C39.1, R54.1
unnamed: C38.2, R58.2
unnamed: C42.1, C45.2, R66.1
unnamed: C43.2, R63.2
unnamed: C44.2, R63.1, R64.1, R65.1
unnamed: C53.2, R67.1, R68.1, R69.1
unnamed: D1.1 (K), D2.2 (A)
unnamed: C8.2, D2.1 (K), D4.2 (A), R9.2, R12.1, R13.1, U1.6 (-)
unnamed: D3.2 (A), D4.1 (K)
unnamed: D5.1 (K), D6.2 (A)
unnamed: C9.2, D6.1 (K), D8.2 (A), R16.1, R17.2, U3.6 (-)
unnamed: D7.2 (A), D8.1 (K)
unnamed: D10.2 (A), D12.1 (K), R48.2, R51.2
unnamed: C24.2, D10.1 (K), D12.2 (A), R45.1, R49.2, U5.9 (-)
unnamed: C23.2, D9.1 (K), D11.2 (A), R44.2, R47.1, U5.6 (-)
unnamed: D9.2 (A), D11.1 (K), R46.2, R50.2
unnamed: C32.1, D13.2 (A), Q5.2 (B), R60.2
unnamed: C51.1, D14.2 (A), Q6.2 (B), R62.2
unnamed: D15.2 (A), J20.1 (+12V)
unnamed: D16.1 (K), J20.4 (-12V)
unnamed: INPUT_GAIN1.3, J2.1
unnamed: J11.2, J16.2
unnamed: Q1.3 (C), R19.2
unnamed: Q1.1 (E), Q4.1 (E), R25.1
unnamed: Q2.3 (C), R20.2
unnamed: Q2.1 (E), Q3.1 (E), R24.1
unnamed: Q3.2 (B), R26.1, R30.2
unnamed: C13.1, Q3.3 (C), R22.2, U4.2 (-)
unnamed: Q4.2 (B), R29.1, R32.2
unnamed: C14.1, Q4.3 (C), R23.2, U4.13 (-)
unnamed: Q5.3 (C), U6.6 (VCO)
unnamed: Q6.3 (C), U8.6 (VCO)
unnamed: C2.2, R2.2, R5.2, R7.1, U1.2 (-)
unnamed: C7.2, R10.2, R11.2, U2.2 (-)
unnamed: C3.2, R3.2, R6.2, U2.6 (-)
unnamed: C11.2, R14.1, R15.1, R18.2, U3.2 (-)
unnamed: C18.2, R26.2, R27.1, R31.1, U4.6 (-)
unnamed: C17.2, R21.1, R28.1, R29.2, R37.2, U4.9 (-)
unnamed: C20.2, R33.2, R35.2, R38.1, U5.2 (-)
unnamed: C19.2, R34.2, R36.2, R39.1, U5.13 (-)
unnamed: C37.2, U6.8 (CC0)
unnamed: C35.2, U6.7 (CC1)
unnamed: C27.2, R52.2, U6.16 (LPF1-IN)
unnamed: C27.1, R53.2, U6.15 (LPF1-OUT)
unnamed: C28.2, R56.2, U6.13 (LPF2-IN)
unnamed: C28.1, R54.2, R55.2, U6.14 (LPF2-OUT)
unnamed: C33.2, U6.10 (OP1-IN)
unnamed: C33.1, U6.9 (OP1-OUT)
unnamed: C30.1, U6.11 (OP2-IN)
unnamed: C30.2, R57.2, U6.12 (OP2-OUT)
unnamed: C29.1, U6.2 (REF)
unnamed: C57.2, U8.8 (CC0)
unnamed: C54.2, U8.7 (CC1)
unnamed: C49.2, R64.2, U8.16 (LPF1-IN)
unnamed: C49.1, R65.2, U8.15 (LPF1-OUT)
unnamed: C50.2, R68.2, U8.13 (LPF2-IN)
unnamed: C50.1, R66.2, R67.2, U8.14 (LPF2-OUT)
unnamed: C55.2, U8.10 (OP1-IN)
unnamed: C55.1, U8.9 (OP1-OUT)
unnamed: C52.1, U8.11 (OP2-IN)
unnamed: C52.2, R69.2, U8.12 (OP2-OUT)
unnamed: C48.1, U8.2 (REF)

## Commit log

2022-01-15 Updating gerbers to rev3
    [dual-digi-delay-B_Cu.gbl, dual-digi-delay-B_Mask.gbs, dual-digi-delay-B_Silkscreen.gbo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]
2022-01-15 Adding signal flow diagram
2022-01-16 Changes after tweaking
    [cv-control.kicad_sch, dual-digi-delay.kicad_sch, outputmix.kicad_sch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]
2022-01-16 Refreshing gerbers and boms after updates
    [dual-digi-delay-B_Cu.gbl, dual-digi-delay-B_Mask.gbs, dual-digi-delay-B_Silkscreen.gbo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]
2022-02-11 Tweaks and fixes for rev 4
    [audioio.kicad_sch, cv-control.kicad_sch, cv-inputs.kicad_sch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]
2022-02-12 Adding image showing delay board construction
2022-02-13 Adding panel graphics files and kicad library
    [dual-digi-delay-frontpanel.kicad_pcb]
2022-02-13 Replot panel gerbers
    [dual-digi-delay-frontpanel-B_Cu.gbl, dual-digi-delay-frontpanel-B_Mask.gbs, dual-digi-delay-frontpanel-B_SilkS.gbo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]
2022-02-13 Replot pcb gerbers
    [dual-digi-delay-B_Cu.gbl, dual-digi-delay-B_Mask.gbs, dual-digi-delay-B_Silkscreen.gbo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]
2022-02-13 Updating schematic
2022-02-16 Adding front panel file for round holes
2022-03-04 Fix J16 silkscreen being on the wrong side
    [audioio.kicad_sch, cv-control.kicad_sch, cv-inputs.kicad_sch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]
2022-03-07 Re export BOMs
    [dual-digi-delay_bom.csv]
2022-03-07 Replot all gerbers and schematics
    [dual-digi-delay-B_Cu.gbl, dual-digi-delay-B_Mask.gbs, dual-digi-delay-B_Silkscreen.gbo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]
2023-07-22 Adding current draw info
2023-12-24 Updating and refreshing kicad project
    [audioio.kicad_sch, cv-control.kicad_sch, cv-inputs.kicad_sch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]
2023-12-24 Tidying files in root folder
    [dual-digi-delay-B_Cu.gbl, dual-digi-delay-B_Mask.gbs, dual-digi-delay-B_Silkscreen.gbo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]
